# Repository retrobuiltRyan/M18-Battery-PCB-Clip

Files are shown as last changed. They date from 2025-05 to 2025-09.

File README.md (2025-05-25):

# M18-Battery-PCB-Clip
Clip-on PCBs with spade terminals compatible with Milwaukee M18 battery packs. 
https://youtu.be/rkWTQf_fx88

P1100437
P1100436
P1100431
P1100419
P1100414

BoM to build whats in video. 

|Item	|Description	|P/N	|$/ Each |	Qty|	Line Total|	Vendor	Notes|
|-----|---|-----|---|----|---|---|
|1|	Battery Spade-Board (PCB to Board solder)|	A100452CT-ND	|0.084	|2|	0.168|	DigiKey	|
|2|	FUSE CLIP BLADE 500V 30A PCB	|36-3557-ND|	0.24|	2|	0.48|	DigiKey	|
|3|	M3 Threaded Insert	|94459A130	|0.275|	2	|0.55|	McMaster|	
|4|	LED 1208	|na	|0.1	|1|	0.1|	DigiKey	optional|
|5|	3.3K Resistor LED 1208|	na|	0.1|	1	|0.1|	DigiKey	optional|
|6|	FUSE AUTO 2A 32VDC BLADE ATO/ATC|	F4192-ND|	0.38|	1|	1|	DigiKey	example 2Amp|
|7|	TERM BLK 2POS SIDE ENT 3.5MM PCB|	732-2747-ND|	0.88	|2	|1.76|	DigiKey	|

Total Cost 4.16

Some ATC fuses with increasing amp rating (digikey P/N) for reference. Do not take this as a suggestion to push this much current through this PCB! 
| PN | Amperage| notes|
|----|---|---|
|F4191-ND| 1 amp| |
|F4192-ND| 2 amp| |
|F4193-ND| 3 amp| |
|F4194-ND| 4 amp| I would not exceed this unless you  monitor temp and duration. |
|F4197-ND| 5 amp| risky|
|F4198-ND| 7.5 amp| uh, not confident on this|
|F4199-ND| 10 amp| haha I do not think 1oz copper will survive|

Safety Claim here: Do not use your batteries in any way outside what the manufacturer claims.

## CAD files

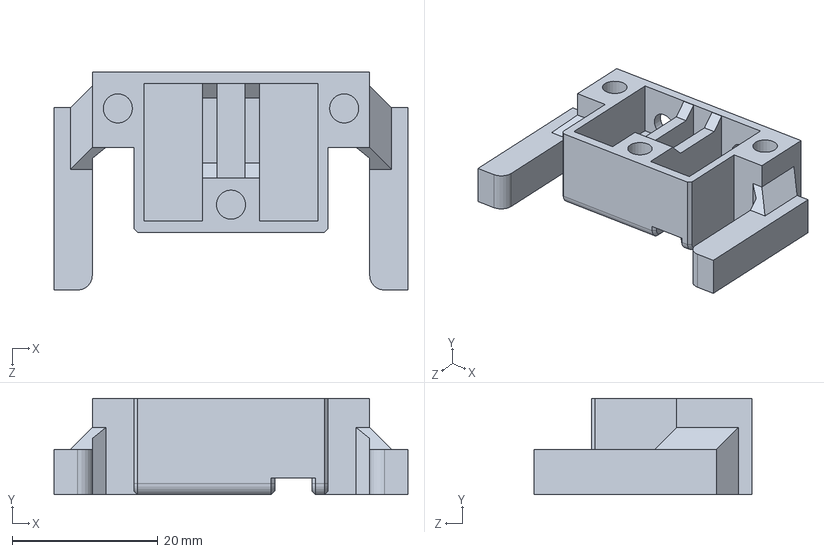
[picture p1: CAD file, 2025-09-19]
M18 Battery Spade Clip Basic for PCB v1.3.SLDPRT
48.5 x 13.2 x 29.9 mm

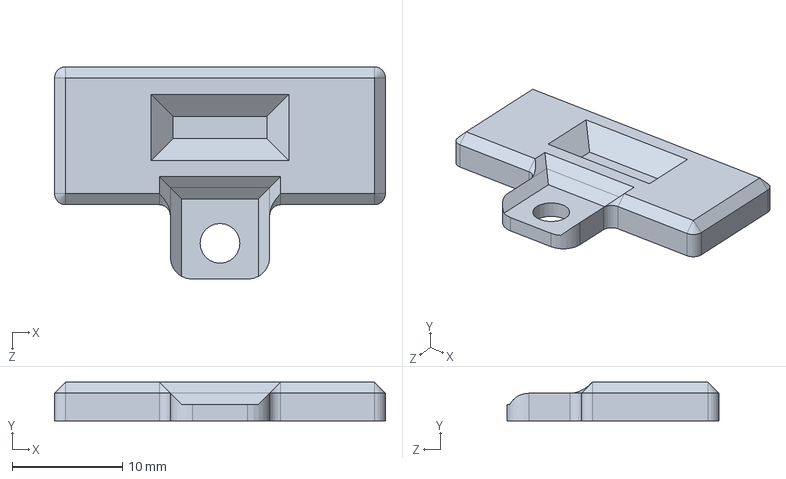
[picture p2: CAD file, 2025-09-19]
M18 PCB safety clip.SLDPRT
30.0 x 3.50 x 19.2 mm

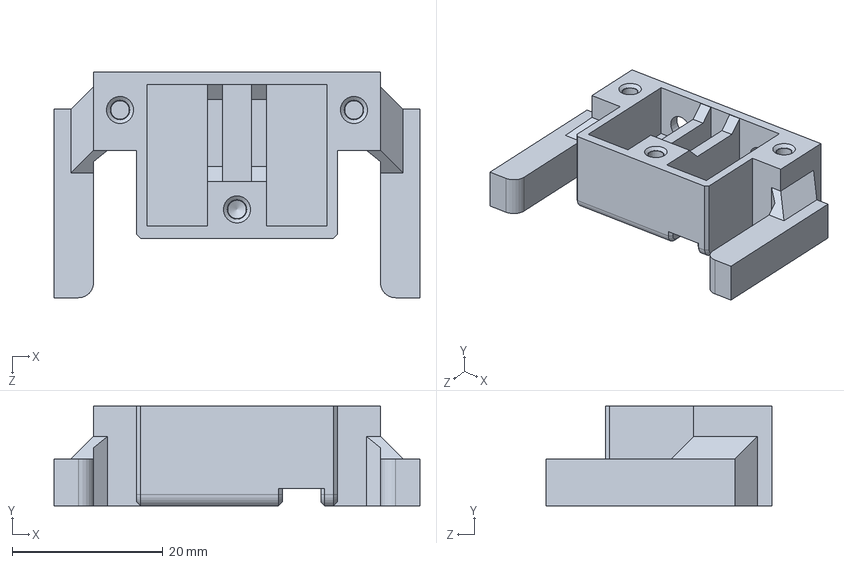
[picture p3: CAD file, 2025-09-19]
M18 Battery Spade Clip Basic for PCB v1.3 3mm TF_screw.SLDPRT
48.5 x 13.2 x 29.9 mm

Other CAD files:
M18 Battery Spade Clip Basic for PCB v1.3 3mm TF_screw.3MF
M18 Battery Spade Clip Basic for PCB v1.3.3MF
M18 PCB safety clip.3MF

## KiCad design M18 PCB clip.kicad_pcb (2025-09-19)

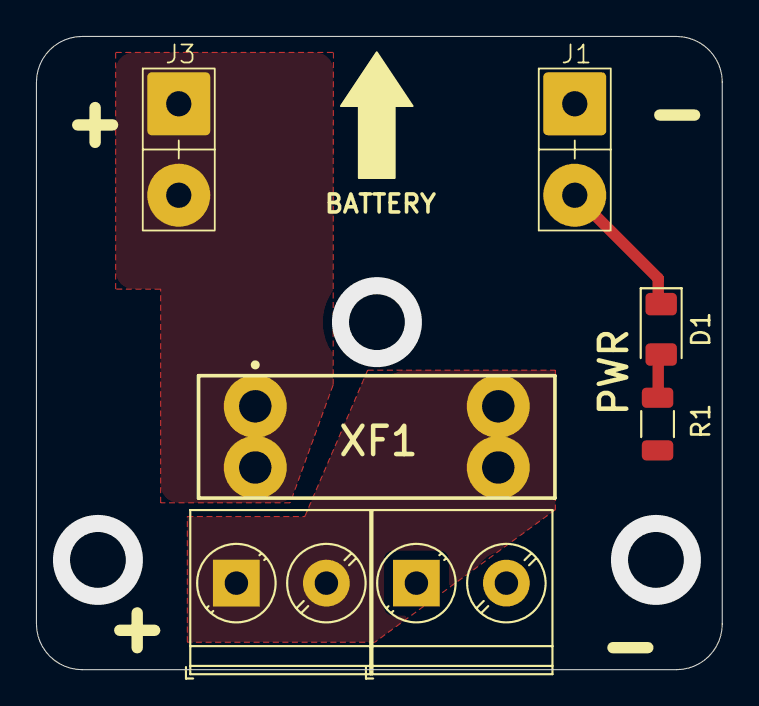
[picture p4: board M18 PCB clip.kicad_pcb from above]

Board: 2 copper layers, 38.1 x 35.2 mm, 7 parts (0 on the bottom side), 4 nets.

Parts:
D1: D; D_1206_3216Metric
J1, J3: CONN QC TAB 0.250 SOLDER
J2, J5: Screw_Terminal_2_P5.00mm; TerminalBlock_Phoenix_PT-1,5-2-5.0-H_1x02_P5.00mm_Horizontal
R1: R_US; R_1206_3216Metric
XF1: 3557-2; FUSE CLIP BLADE 500V 30A PCB

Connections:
/VFuse: J5.1, J5.2, R1.1, XF1.3, XF1.4
GND: D1.1 (K), J1.1, J1.2, J2.1, J2.2
unnamed: D1.2 (A), R1.2
VCC: J3.1, J3.2, XF1.1, XF1.2

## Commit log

2024-10-27 Add files via upload
    Some older 3D printer might need this model scaled +1% X & Y to accommodate PLA shrinkage.
    [M18 Battery Spade Clip Full for PCB.3MF]
2024-11-01 Update README.md
    Extra ATC fuse P/Ns added
2024-11-01 Update README.md
    table zed the BoM
2024-12-15 Some tolerances adjustment for older printers
    Print 100% scale on a good printer (X1C)
    Print 101% X on older, not as a great printer (Ender 3)
    Assumes PLA material for both.
    [M18 Battery Spade Clip Basic for PCB v1.2.3MF]
2024-12-16 M3 TF screw
    Thread Forming M3 screws for plastic. More economical (parts, labor) vs. threaded inserted and M3 machine screws.
    [M18 Battery Spade Clip Basic for PCB v1.3 3mm TF_screw.3MF]
2024-12-16 Alignment clip for battery
    Alignment clip for battery (optional, but nice). Requires 3D printing and M3 threaded inserts with M3x6mm screws.
    [M18 Battery Spade Clip Basic for PCB v1.3.3MF]
2025-01-03 Safety Clip (bumper)
    Cover those live terminals because it might be a problem if not insulated.
    [M18 PCB safety clip.3MF]
2025-09-19 PCB design files (kicad v8.x)
    [M18 PCB clip.kicad_pcb, M18 PCB clip.kicad_sch]
2025-09-19 CAD design files (solidworks 2024 )
    [M18 Battery Spade Clip Basic for PCB v1.3 3mm TF_screw.SLDPRT, M18 Battery Spade Clip Basic for PCB v1.3.SLDPRT, M18 PCB safety clip.SLDPRT]
